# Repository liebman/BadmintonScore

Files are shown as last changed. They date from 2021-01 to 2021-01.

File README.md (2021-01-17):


# Badminton Scoreboard

A simple LED Matrix scoreboard for badminton implemented for fun because some friends host a Badminton party in most years.

## Usage

On power on you hve to choose the game score limit between a normal 21 point game and a short 15 point game.  Use the button on the same side as the game limit you want.  After that a short press on either side button increments the score on that side, a long press decrements the score in case of a mistake.  A short press on the middle button swaps the score from side to side, a long press will reset the score back to 0 and a very long 10-15 seconds will perform a reset allowing you to change the game limit.

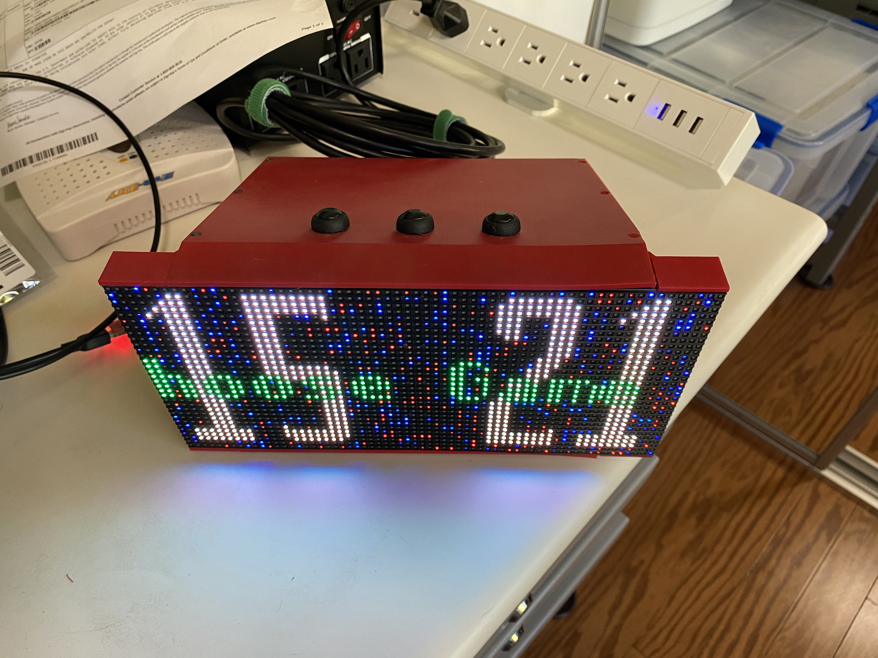
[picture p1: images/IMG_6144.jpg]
Choose

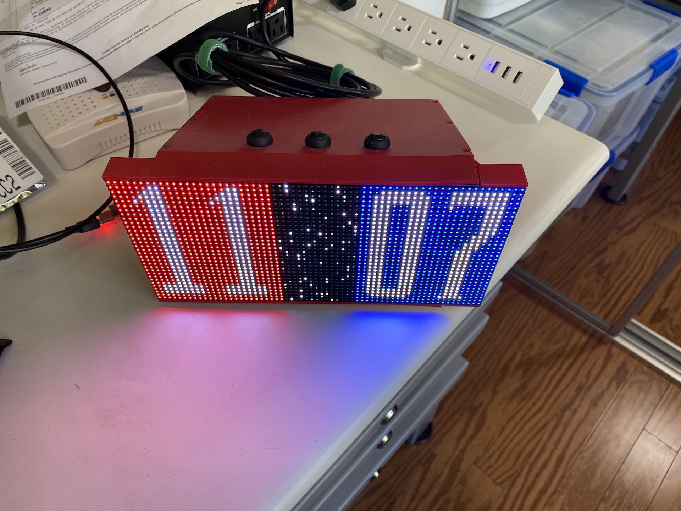
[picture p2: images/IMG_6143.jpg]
Score


[src](src) Contains the code for the Badminton Scoreboard

[ScoreBoard](ScoreBoard) contains the schematic and board designs in Eagle cad.

[3d](3d) contains the STL files for the enclosure.

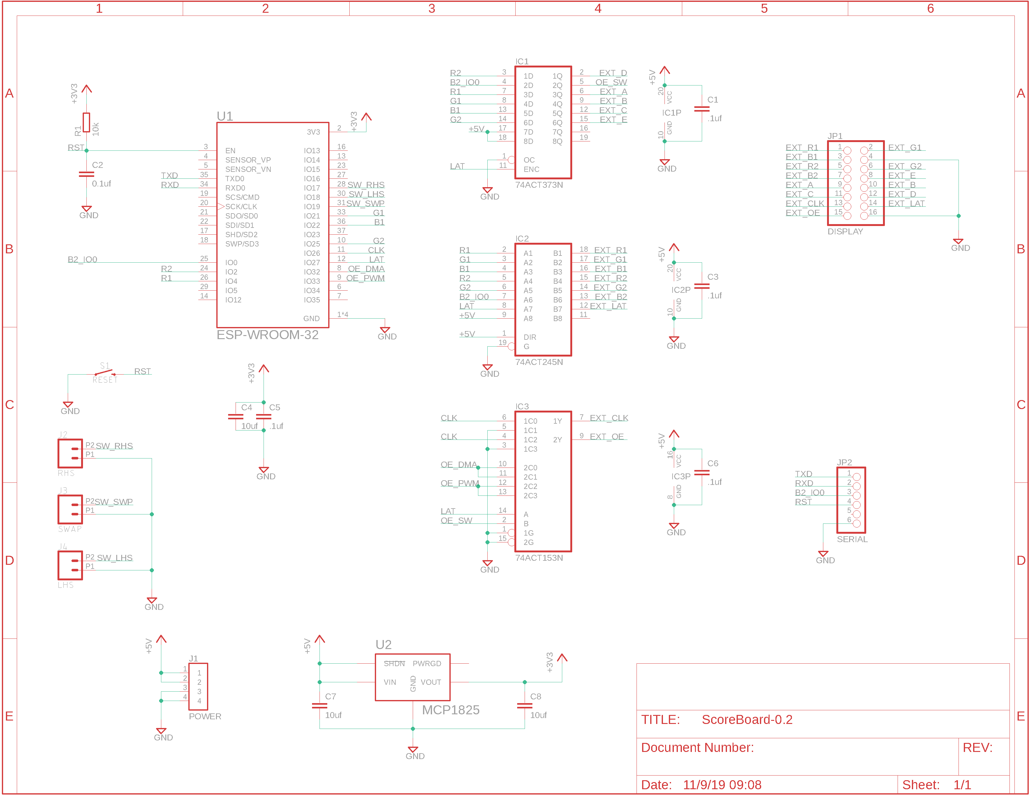
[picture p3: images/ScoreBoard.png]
Schematic


## Misc Parts

P4 64x32 LED Display w/HUB75 interface

[50 Watt 5v power supply](https://smile.amazon.com/gp/product/B019GYOCMM/ref=ppx_yo_dt_b_search_asin_title?ie=UTF8&psc=1)

3 SPST Buttons

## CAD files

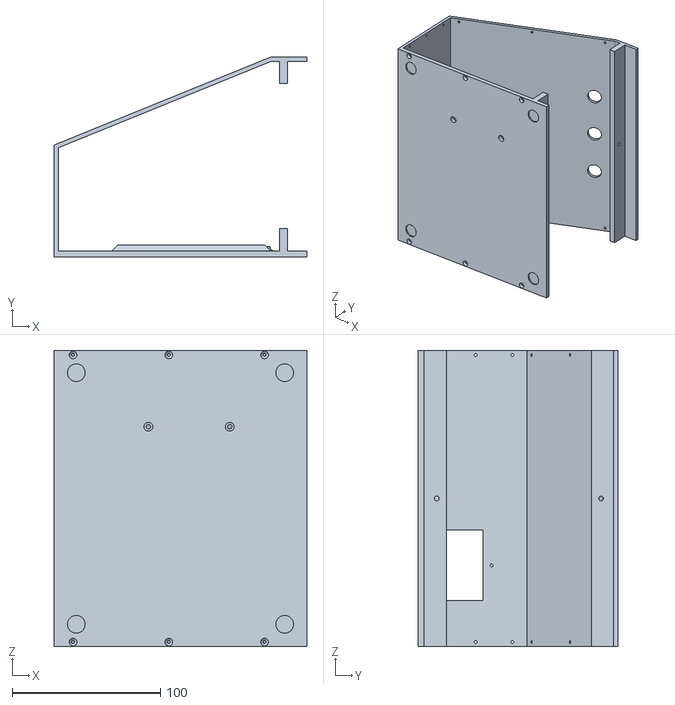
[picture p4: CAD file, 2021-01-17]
3d/ScoreboardBody-v61.stl
170.8 x 134.8 x 200.0

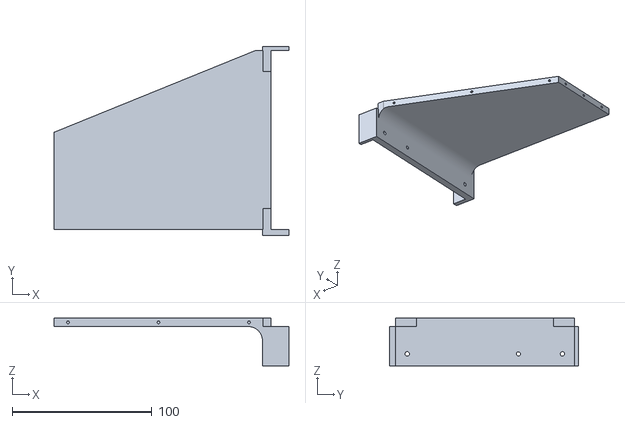
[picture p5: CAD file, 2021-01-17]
3d/RightWing-v61.stl
168.0 x 134.8 x 34.0

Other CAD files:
3d/LeftWing-v61.stl

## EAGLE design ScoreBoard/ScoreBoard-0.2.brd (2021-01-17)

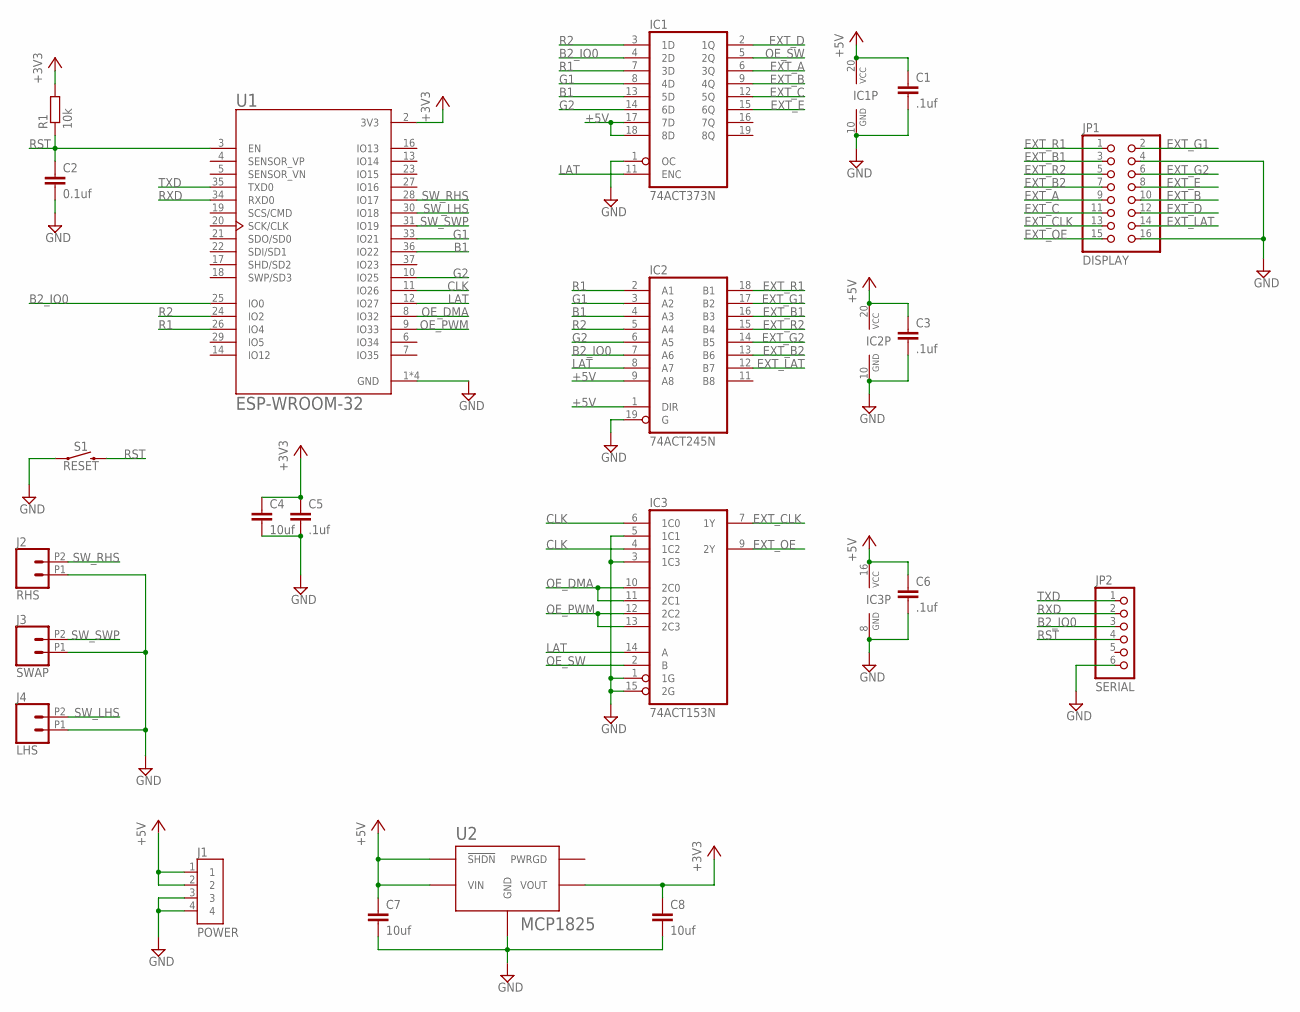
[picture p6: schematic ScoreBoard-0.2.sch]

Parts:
C1, C3, C5, C6: .1uf; C025-025X050
C2: 0.1uf; C025-025X050
C4, C7, C8: 10uf; C050-025X075
IC1: 74ACT373N; DIL20
IC2: 74ACT245N; DIL20
IC3: 74ACT153N; DIL16
J1: POWER; TE_1-1123723-4
J2: RHS; 1X02_2.54_SCREWTERM
J3: SWAP; 1X02_2.54_SCREWTERM
J4: LHS; 1X02_2.54_SCREWTERM
JP1: DISPLAY; 2X08
JP2: SERIAL; 1X06/90
R1: 10k; 0204/7
S1: RESET; TACTILE_SWITCH_PTH_6.0MM
U1: ESP-WROOM-32; MODULE_ESP-WROOM-32
U2: MCP1825; SOT-223-5

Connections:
+3V3: C4.1, C5.1, C8.1, R1.2, U1.2 (3V3), U2.P$4 (VOUT)
+5V: C1.1, C3.1, C6.1, C7.1, IC1.17 (7D), IC1.18 (8D), IC1.20 (VCC), IC2.1 (DIR), IC2.9 (A8), IC2.20 (VCC), IC3.16 (VCC), J1.1, J1.2, U2.P$1 (!SHDN), U2.P$2 (VIN)
B1: IC1.13 (5D), IC2.4 (A3), U1.36 (IO22)
B2_IO0: IC1.4 (2D), IC2.7 (A6), JP2.3, U1.25 (IO0)
CLK: IC3.4 (1C2), IC3.6 (1C0), U1.11 (IO26)
EXT_A: IC1.6 (3Q), JP1.9
EXT_B: IC1.9 (4Q), JP1.10
EXT_B1: IC2.16 (B3), JP1.3
EXT_B2: IC2.13 (B6), JP1.7
EXT_C: IC1.12 (5Q), JP1.11
EXT_CLK: IC3.7 (1Y), JP1.13
EXT_D: IC1.2 (1Q), JP1.12
EXT_E: IC1.15 (6Q), JP1.8
EXT_G1: IC2.17 (B2), JP1.2
EXT_G2: IC2.14 (B5), JP1.6
EXT_LAT: IC2.12 (B7), JP1.14
EXT_OE: IC3.9 (2Y), JP1.15
EXT_R1: IC2.18 (B1), JP1.1
EXT_R2: IC2.15 (B4), JP1.5
G1: IC1.8 (4D), IC2.3 (A2), U1.33 (IO21)
G2: IC1.14 (6D), IC2.6 (A5), U1.10 (IO25)
GND: C1.2, C2.2, C3.2, C4.2, C5.2, C6.2, C7.2, C8.2, IC1.1 (OC), IC1.10 (GND), IC2.10 (GND), IC2.19 (G), IC3.1 (1G), IC3.3 (1C3), IC3.5 (1C1), IC3.8 (GND), IC3.15 (2G), J1.3, J1.4, J2.P1 (1), J3.P1 (1), J4.P1 (1), JP1.4, JP1.16, JP2.6, S1.1, U1.1 (GND), U1.1.1 (GND), U1.15 (GND), U1.38 (GND), U2.P$3 (GND), U2.P$6 (GND)
LAT: IC1.11 (ENC), IC2.8 (A7), IC3.14 (A), U1.12 (IO27)
OE_DMA: IC3.10 (2C0), IC3.11 (2C1), U1.8 (IO32)
OE_PWM: IC3.12 (2C2), IC3.13 (2C3), U1.9 (IO33)
OE_SW: IC1.5 (2Q), IC3.2 (B)
R1: IC1.7 (3D), IC2.2 (A1), U1.26 (IO4)
R2: IC1.3 (1D), IC2.5 (A4), U1.24 (IO2)
RST: C2.1, JP2.4, R1.1, S1.3 (2), U1.3 (EN)
RXD: JP2.2, U1.34 (RXD0)
SW_LHS: J4.P2 (2), U1.30 (IO18)
SW_RHS: J2.P2 (2), U1.28 (IO17)
SW_SWP: J3.P2 (2), U1.31 (IO19)
TXD: JP2.1, U1.35 (TXD0)

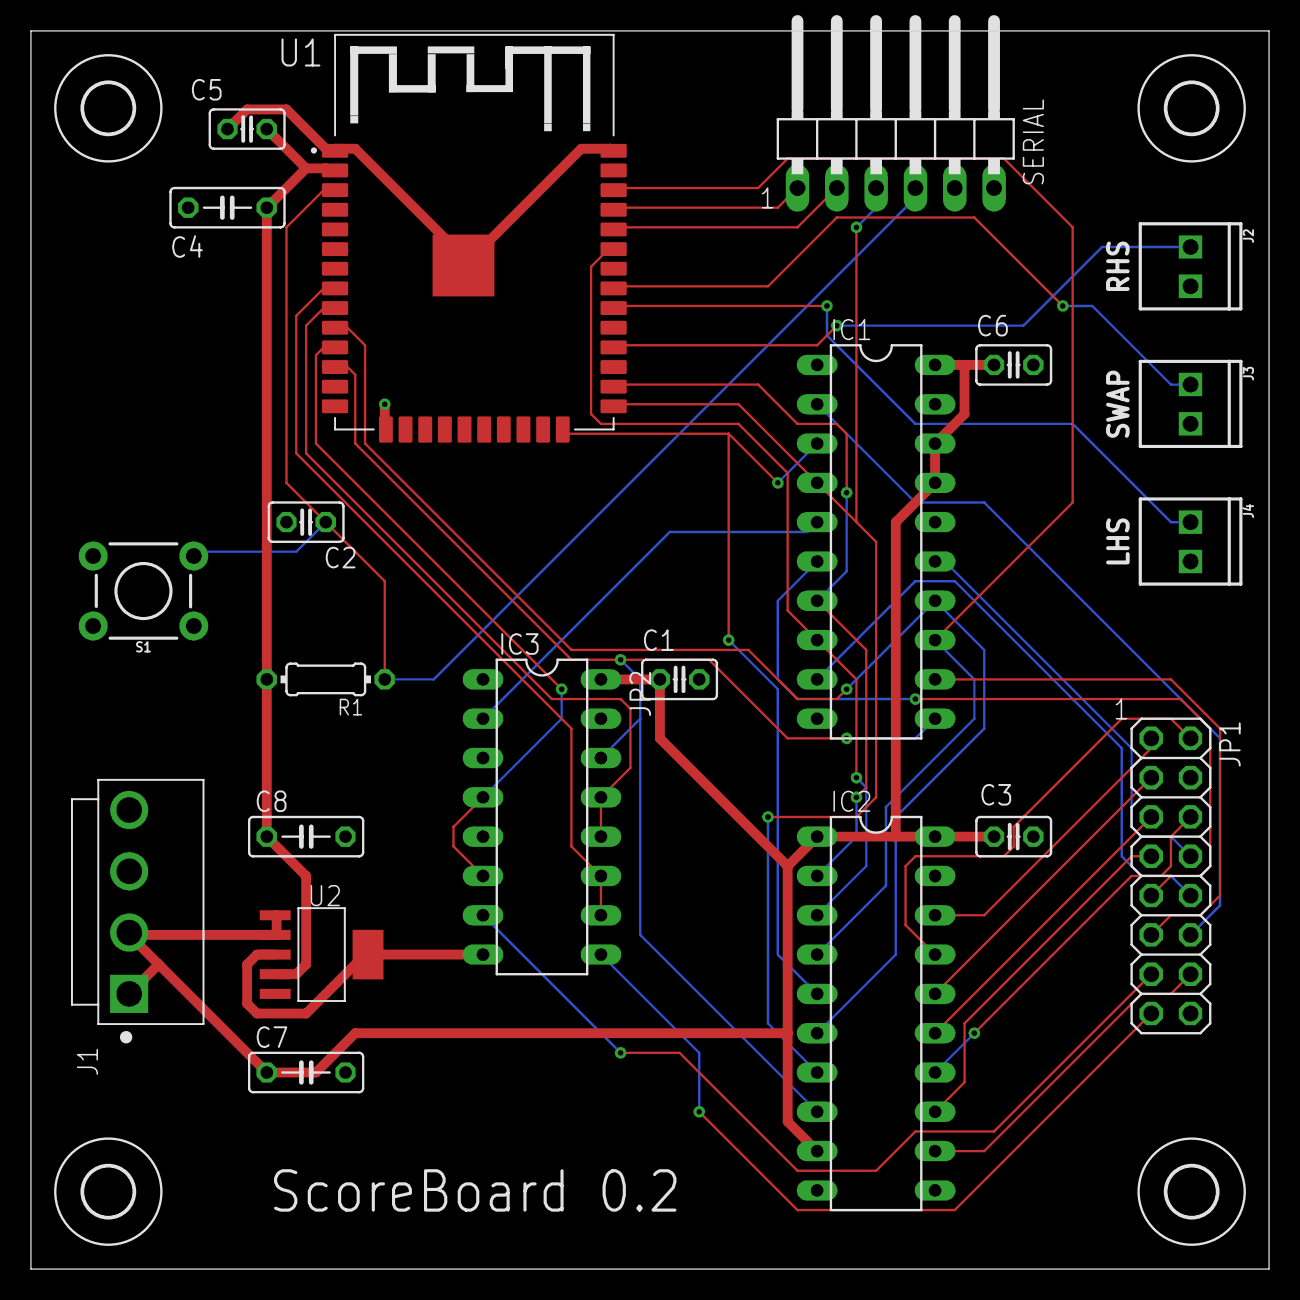
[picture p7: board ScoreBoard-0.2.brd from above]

Board: 2 copper layers, 80.0 x 80.0 mm, 25 parts (0 on the bottom side), 34 nets.

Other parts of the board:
U$1, U$2, U$3, U$4: 3,2

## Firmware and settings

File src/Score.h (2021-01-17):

/**
 * @file Score.h
 * @author Christoper B. Liebman
 * @brief Manages score values
 * @version 0.1
 * @date 2019-10-21
 * 
 * Copyright (c) 2020 Christoper B. Liebman
 *
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
 * At 20 all, the side which gains a 2 point lead first, wins that game.
 * At 29 all, the side scoring the 30th point, wins that game.
 */
#ifndef SCORE_H_
#define SCORE_H_

#define DEFAULT_SCORE_LIMIT 21
#define DEFAULT_SCORE_MAX_LIMIT 30

class Score
{
public:
    // when not swapped RED is on the LHS
    enum Team {RED = 0, BLUE = 1, NUM_TEAMS};
    enum Side {LHS = 0, RHS = 1, NUM_SIDES};
    Score();
    virtual ~Score();
    void swap();
    void reset();
    void setLimits(int limit, int max_limit);
    Side getSide(Team team);
    Team getTeam(Side side);
    Team getLeader();
    int getScore(Side side);
    void incrementScore(Side side, int increment);
    bool isGameOver();

private:
    volatile int  _limit;
    volatile int  _max_limit;
    volatile int  _score[NUM_TEAMS];
    volatile bool _swappped;
};

#endif /* SCORE_H_ */

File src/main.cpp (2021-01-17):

/**
 * @file main.cpp
 * @author Christopher B. Liebman
 * @brief 
 * @version 0.1
 * @date 2019-10-21
 * 
 * Copyright (c) 2020 Christoper B. Liebman
 *
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
 */
#include "App.h"
#include "WebApp.h"
#include "Buttons.h"
#include "Display.h"
#include <functional>
#include <SPIFFS.h>
#include "Config.h"
#include "WiFiSetup.h"
#include "Log.h"
#include "DLogPrintWriter.h"

const uint8_t SCORE_RHS_PIN  = 17;
const uint8_t SCORE_LHS_PIN  = 18;
const uint8_t SCORE_SWAP_PIN = 19;

static App& app = App::getInstance();
static Display display(app);
static Buttons buttons(app, SCORE_LHS_PIN, SCORE_RHS_PIN, SCORE_SWAP_PIN);

DLog& dlog = DLog::getLog();
Config config;

#ifdef USE_NETWORK_BY_DEFAULT
const bool DEFAULT_USE_NETWORK = true;
#else
const bool DEFAULT_USE_NETWORK = false;
#endif

#ifdef SHOW_MEMORY_USAGE
#define MEMORY_USAGE(s)  printMemInfo(s)
void printMemInfo(const char* label)
{
    static const char* TAG = "printMemInfo";
    uint32_t heap_size = ESP.getHeapSize();
    uint32_t heap_free = ESP.getFreeHeap();
    uint32_t min_free = ESP.getMinFreeHeap();
    uint32_t largest_free = ESP.getMaxAllocHeap();
    dlog.info(TAG, "%s - size:%u free:%u largest:%u minfree:%u", label, heap_size, heap_free, largest_free, min_free);
}
#else
#define MEMORY_USAGE(s) 
#endif

static void logTimeFirst(DLogBuffer& buffer, DLogLevel level)
{
    (void)level; // not used
    const char* name = pcTaskGetTaskName(NULL);
    uint32_t core =  xPortGetCoreID();
    //buffer.printf("%1.3f ", millis()/1000.0);
    buffer.printf("%010lu %u:%s ", millis(), core, name);
}

void initWiFi(bool force_config)
{
        MEMORY_USAGE("before WiFiSetup");
        WiFiSetup wfs(config, display, true);
        wfs.connect(force_config);
    
        MEMORY_USAGE("before WebApp");
        display.message("WebApp");
        WebApp& wapp = WebApp::getInstance();
        wapp.begin(&config, &SPIFFS, "/scoreboard");
}

void setup() {
    static const char* TAG = "setup";
    Serial.begin(115200);
    dlog.begin(new DLogPrintWriter(Serial));
    dlog.setPreFunc(&logTimeFirst);
    delay(200);
    dlog.info(TAG, "Starting!");
    MEMORY_USAGE("setup");

    buttons.begin();

    display.begin("Scoreboard 1.0");
    app.mode(AppMode::STARTING);
    display.render();

    MEMORY_USAGE("befor Config");
    display.message("Config");
    config.begin();
    bool force_config = false;
    if (!config.load())
    {
        dlog.info(TAG, "config failed to load, forcing config if wifi enabled");
        force_config = true;
    }
    MEMORY_USAGE("after Config");

    bool start_network = DEFAULT_USE_NETWORK;
    if (config.getStartWiFi())
    {
        start_network = true;
    }

    if (digitalRead(SCORE_LHS_PIN) == 0 && digitalRead(SCORE_RHS_PIN) == 0)
    {
        force_config = true;
    }

    if (digitalRead(SCORE_SWAP_PIN) == 0)
    {
        start_network = !start_network;
    }

    if (start_network)
    {
        initWiFi(force_config);
    }

    //
    // any app change notifies the display
    //
    MEMORY_USAGE("before app.onChange");
    app.onChange(std::bind(&Display::render, &display));

    MEMORY_USAGE("setup done");
}

void loop()
{
#ifdef SHOW_MEMORY_USAGE
    static uint32_t last_memory_display = 0;
    uint32_t now = millis();
    if ((now - last_memory_display) > SHOW_MEMORY_USAGE)
    {
        MEMORY_USAGE("loop");
        last_memory_display = now;
    }
#endif

    // soft reset: hold swap for 10ish seconds
    if (buttons.isReset())
    {
        ESP.restart();
    }

    switch (app.mode())
    {
    case AppMode::STARTING:
        if (!display.isScrolling())
        {
            app.mode(AppMode::CHOOSING);
        }
        break;

    case AppMode::CHOOSING:
        // state change here happens in choice()
        break;

    case AppMode::RUNNING:
        if (app.isGameOver())
        {
            app.mode(AppMode::GAME_OVER);
        }
        break;

    case AppMode::GAME_OVER:
        if (!app.isGameOver())
        {
            app.mode(AppMode::RUNNING);
        }
        break;
    }
    delay(1);
}

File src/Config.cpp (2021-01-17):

/*
 * Config.cpp
 *
 *  Created on: Jun 10, 2018
 *      Author: chris.l
 *
 * Copyright (c) 2020 Christoper B. Liebman
 *
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
 * THE SOFTWARE IS PROVIDED "AS IS", WITHOUT WARRANTY OF ANY KIND, EXPRESS OR
 * IMPLIED, INCLUDING BUT NOT LIMITED TO THE WARRANTIES OF MERCHANTABILITY,
 * FITNESS FOR A PARTICULAR PURPOSE AND NONINFRINGEMENT. IN NO EVENT SHALL THE
 * AUTHORS OR COPYRIGHT HOLDERS BE LIABLE FOR ANY CLAIM, DAMAGES OR OTHER
 * LIABILITY, WHETHER IN AN ACTION OF CONTRACT, TORT OR OTHERWISE, ARISING FROM,
 * OUT OF OR IN CONNECTION WITH THE SOFTWARE OR THE USE OR OTHER DEALINGS IN THE
 * SOFTWARE.
 */

#include "Config.h"
#include <SPIFFS.h>
#include <FS.h>
#include "Log.h"
#include "ArduinoJson.h"

static const char* TAG = "Config";
static const char* CONFIG_FILE = "/Config.json";


Config::Config() : _hostname(), _enable_password(), _start_wifi()
{
}

Config::~Config()
{
}

bool Config::begin()
{
    dlog.info(TAG, "begin: Mounting SPIFFS");

    if (!SPIFFS.begin())
    {
        dlog.warning(TAG, "begin: Formatting SPIFFS!!!!!");
        if (SPIFFS.format())
        {
            dlog.error(TAG, "begin: SPIFFS format failed!");
            return false;
        }
        dlog.info(TAG, "begin: mounting SPIFFS after format!");
        if (!SPIFFS.begin())
        {
            dlog.error(TAG, "begin: SPIFFS mount failed!!!!");
            return false;
        }
    }

    return true;
}

bool Config::load()
{
    dlog.info(TAG, "load: file: '%s'", CONFIG_FILE);

    if (!SPIFFS.exists(CONFIG_FILE))
    {
        dlog.warning(TAG, "load: config file does not exist!");
        return false;
    }

    File f = SPIFFS.open(CONFIG_FILE, "r");
    if (!f)
    {
        dlog.error(TAG, "load: failed to open config file!");
        return false;
    }

    StaticJsonDocument<512> doc;

    dlog.debug(TAG, "load: parsing file contents");
    DeserializationError err = deserializeJson(doc, f);
    if (err)
    {
        dlog.error(TAG, "deserializeJson() failed: '%s", err.c_str());
        return false;
    }
    f.close();

    _hostname        = doc["hostname"].as<String>();
    _enable_password = doc["enable_password"].as<String>();
    _start_wifi      = doc["start_wifi"];

    dlog.info(TAG, "load: hostname:'%s', enable:'%s', start_wifi:'%s'",
                   _hostname.c_str(), _enable_password.c_str(), _start_wifi?"true":"false");
    dlog.info(TAG, "load: config loaded!");
    return true;
}

void Config::save()
{
    dlog.info(TAG, "save: file: '%s'", CONFIG_FILE);

    File f = SPIFFS.open(CONFIG_FILE, "w");

    StaticJsonDocument<512> doc;

    doc["hostname"]        = _hostname;
    doc["enable_password"] = _enable_password;
    doc["start_wifi"]      = _start_wifi;

    serializeJson(doc, f);
    f.close();

    dlog.info(TAG, "save: config saved");
}

const String& Config::getHostname()
{
    return _hostname;
}

void Config::setHostname(const String& host)
{
    _hostname = host;
}
const String& Config::getEnablePassword()
{
    return _enable_password;
}

void Config::setEnablePassword(const String& password)
{
    _enable_password = password;
}

bool Config::getStartWiFi()
{
    return _start_wifi;
}

void Config::setStartWiFi(bool start_wifi)
{
    _start_wifi = start_wifi;
}

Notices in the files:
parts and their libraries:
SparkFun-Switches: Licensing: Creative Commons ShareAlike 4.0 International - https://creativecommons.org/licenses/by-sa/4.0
